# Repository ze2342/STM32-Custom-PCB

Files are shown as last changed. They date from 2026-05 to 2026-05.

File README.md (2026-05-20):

# STM32 Custom PCB Design

A custom STM32-based embedded system PCB designed in KiCad following professional PCB design practices inspired by Phil’s Lab.

## Overview

This project demonstrates the complete workflow of designing a professional embedded STM32 PCB from scratch instead of using ready-made development boards like the STM32 Blue Pill.

The PCB was designed with focus on:
- Clean routing
- Ground plane implementation
- Proper power distribution
- Compact embedded hardware layout
- Professional PCB engineering workflow

---

## Features

- STM32 microcontroller
- USB interface
- SWD programming/debugging header
- UART communication header
- BOOT mode switch
- I2C header
- Ground plane implementation
- Mounting holes
- Fully clean DRC
  - 0 Errors
  - 0 Warnings

---

## Tools Used

- KiCad
- STM32
- Git & GitHub

---

## PCB Preview

### Schematic
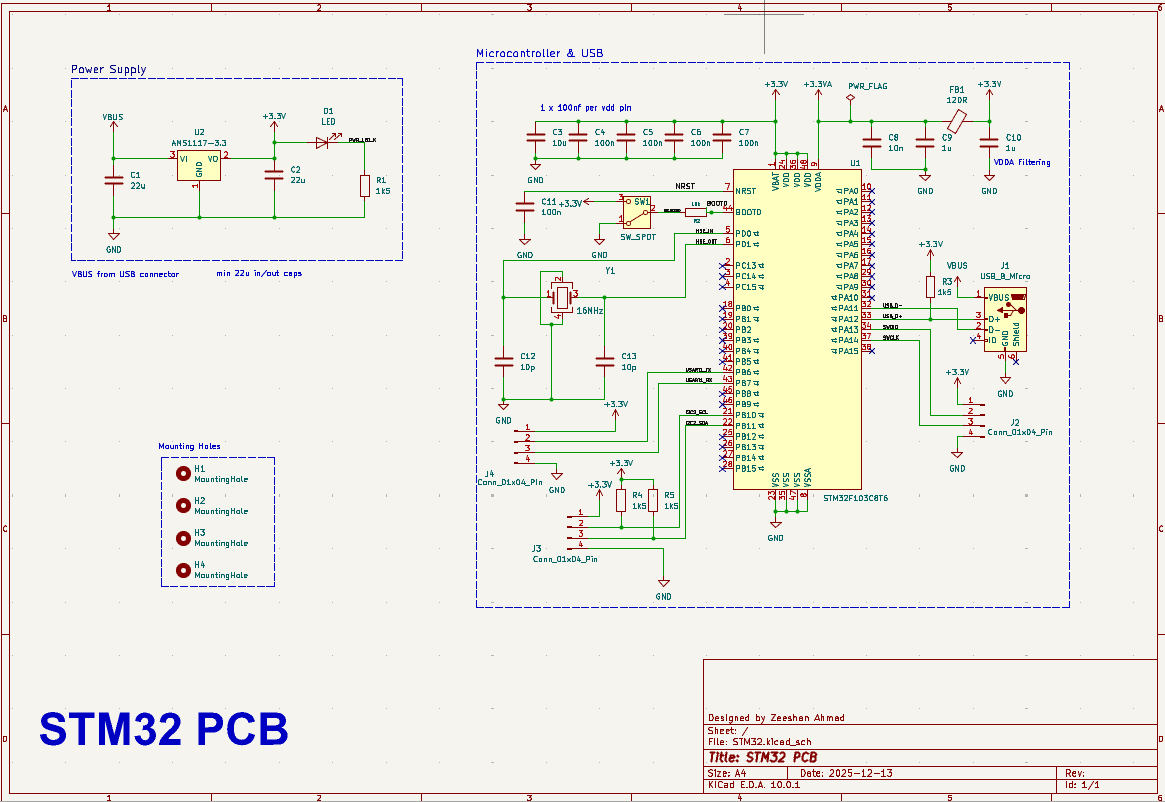
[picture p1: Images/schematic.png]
Schematic


### PCB Layout
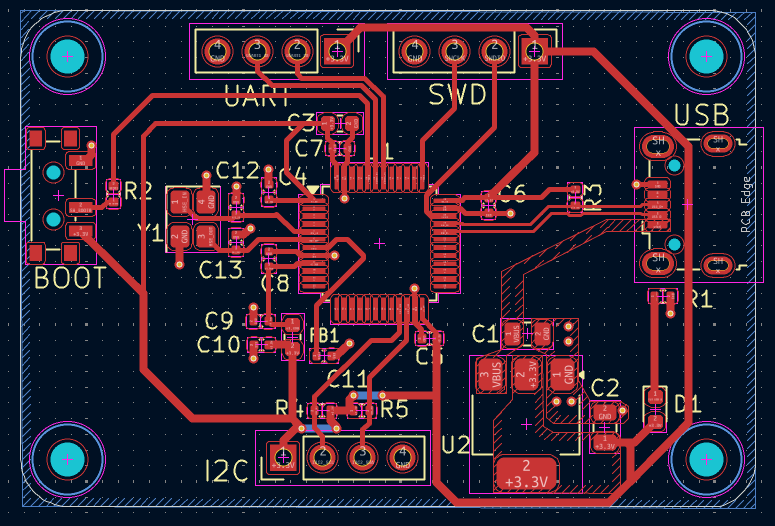
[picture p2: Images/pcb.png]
PCB Layout


### 3D View
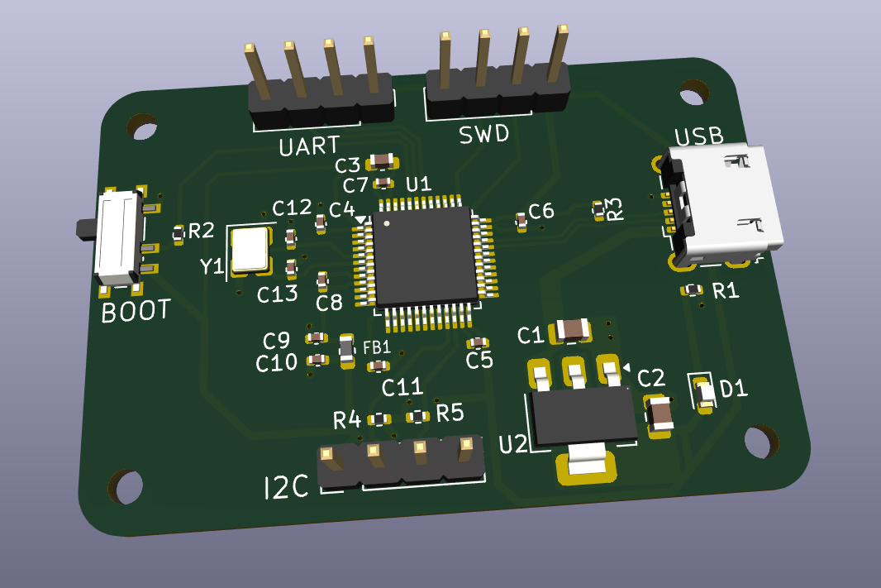
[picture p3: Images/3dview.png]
3D View


## Learning Outcomes

Through this project I learned:

- STM32 hardware design
- PCB routing techniques
- Ground plane usage
- Design Rule Check (DRC)
- Via sizing and routing
- Footprint customization
- USB and UART interfacing
- Embedded hardware workflow
- GitHub project management

---

## Folder Structure

```text
STM32-CUSTOM-BOARD/
│
├── KiCad/
├── Images/
├── README.md
└── LICENSE
```

---

## Future Improvements

- Add more GPIO breakout headers
- Add onboard sensors
- Add firmware examples
- Create a custom enclosure
- Add power protection circuitry

---

## Inspiration

This project was inspired by Phil’s Lab embedded hardware and PCB design tutorials.

---

## Author

Zeeshan Ahmad

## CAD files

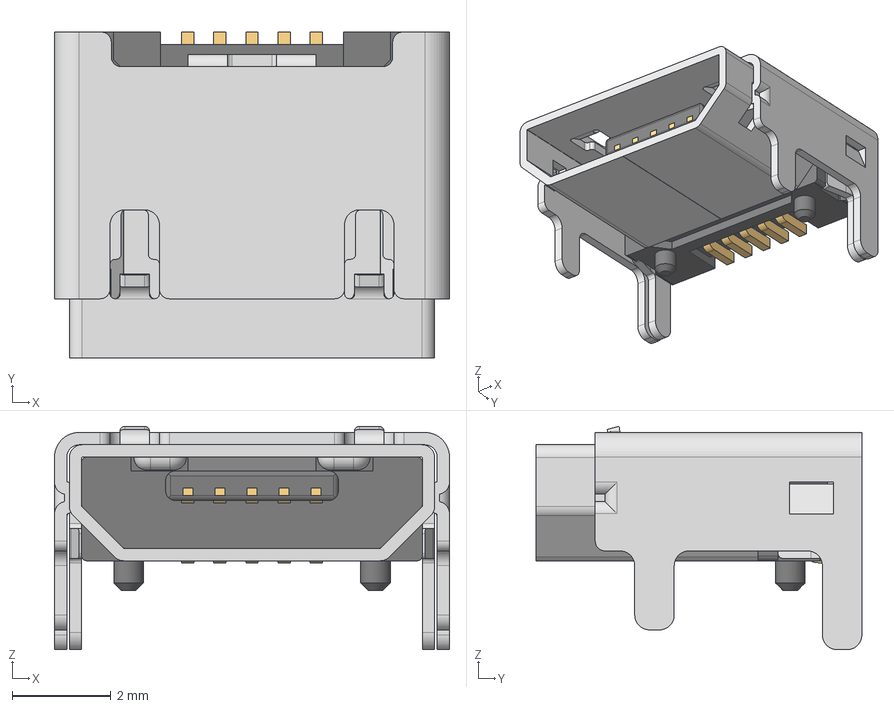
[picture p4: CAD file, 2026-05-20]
KiCad/629105150521 (rev1).stp
8.00 x 6.60 x 4.52 mm
629105150521_Housing
629105150521_Pin1 x 4
629105150521_Pin2
629105150521_Shielding2
629105150521_Shielding

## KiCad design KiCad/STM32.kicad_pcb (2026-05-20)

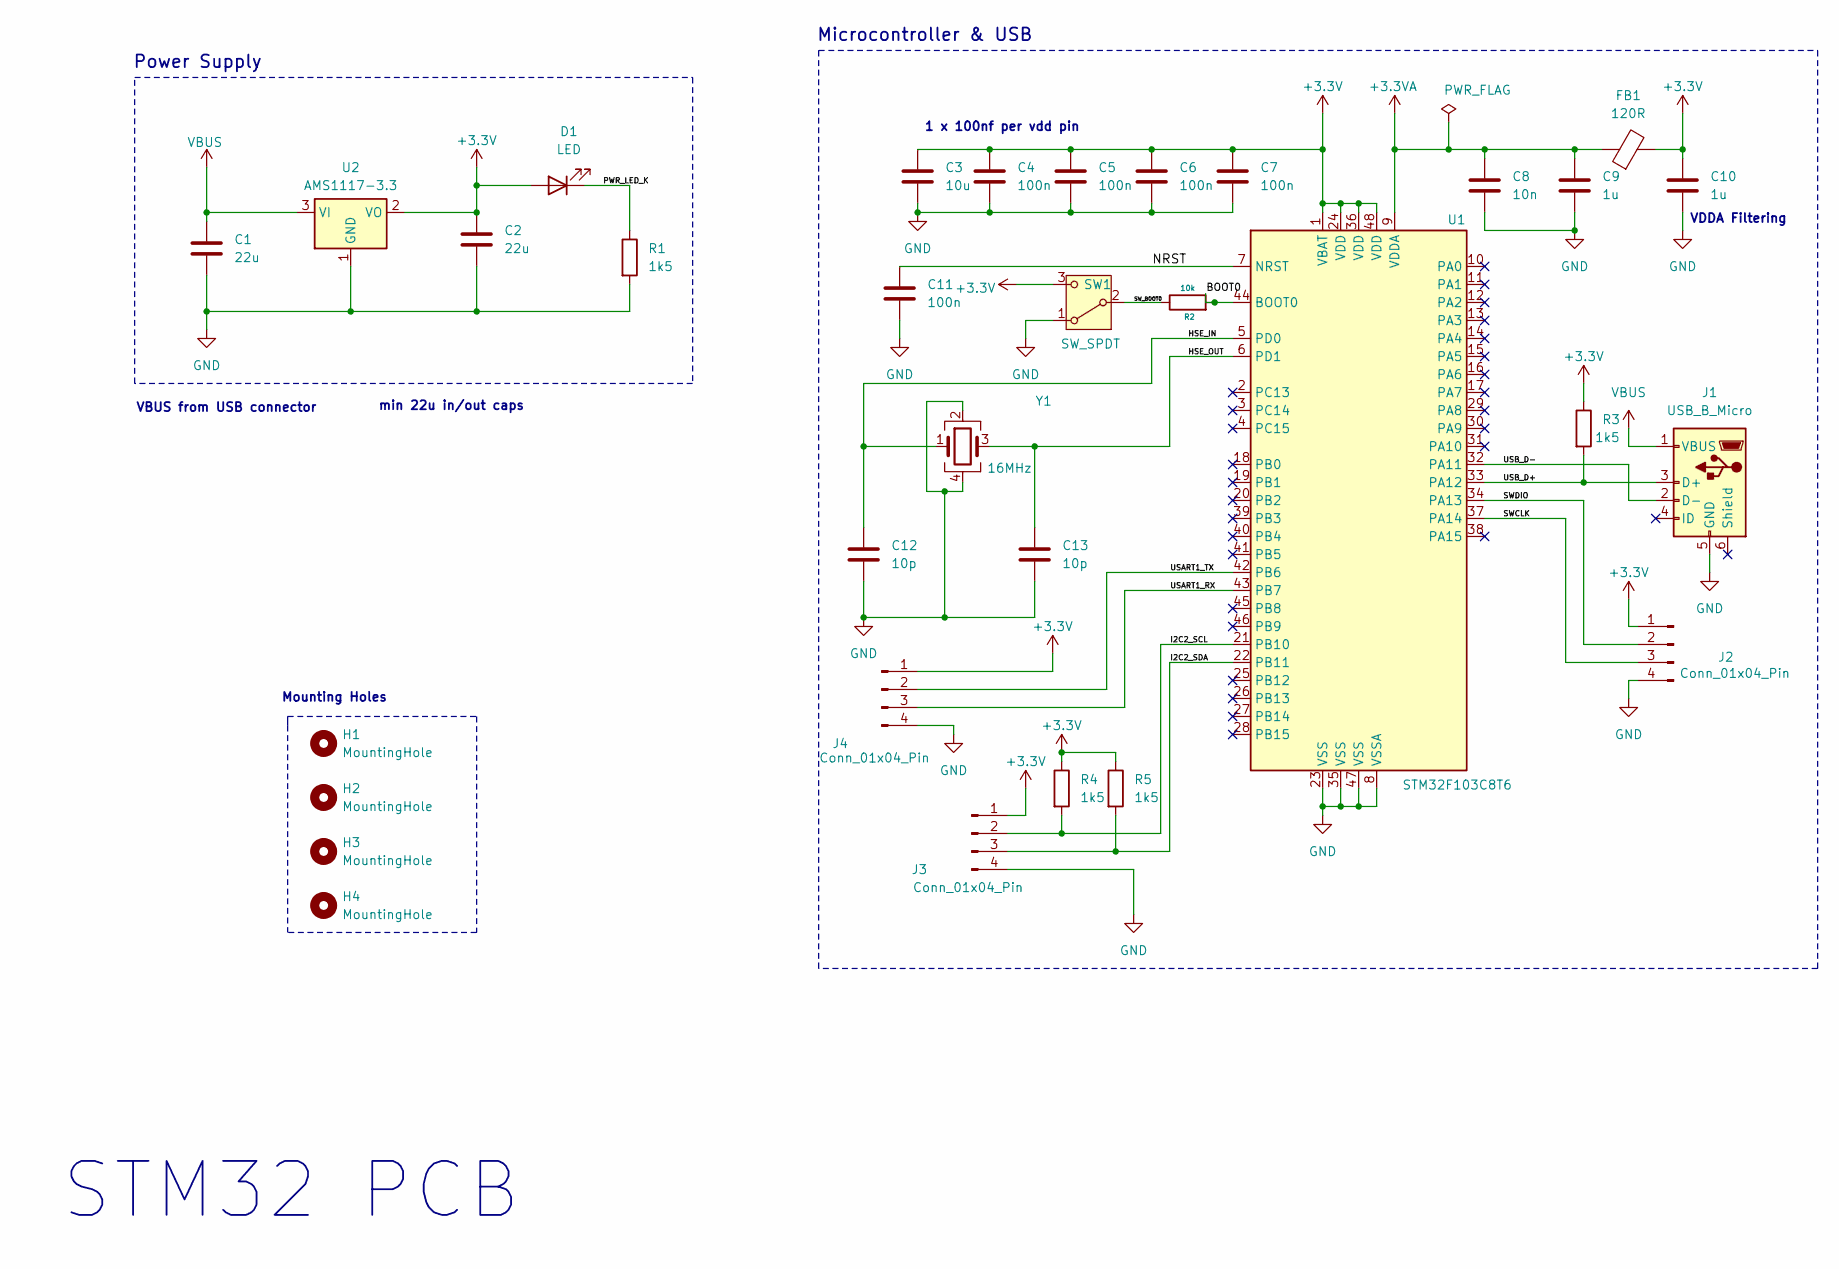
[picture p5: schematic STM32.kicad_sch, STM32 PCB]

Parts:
C1, C2: 22u; C_0805_2012Metric
C3: 10u; C_0603_1608Metric
C4, C5, C6, C7, C11: 100n; C_0402_1005Metric
C8: 10n; C_0402_1005Metric
C9, C10: 1u; C_0402_1005Metric
C12, C13: 10p; C_0402_1005Metric
D1: LED; LED_0603_1608Metric
FB1: 120R; L_0603_1608Metric
H1, H2, H3, H4: MountingHole; MountingHole_2.2mm_M2
J1: USB_B_Micro; USB_Micro-B_Wuerth_629105150521
J2, J3, J4: Conn_01x04_Pin; PinHeader_1x04_P2.54mm_Vertical
R1, R3, R4, R5: 1k5; R_0402_1005Metric
R2: 10k; R_0402_1005Metric
SW1: SW_SPDT; SW_SPDT_PCM12
U1: STM32F103C8T6; LQFP-48_7x7mm_P0.5mm
U2: AMS1117-3.3; SOT-223-3_TabPin2
Y1: 16MHz; Crystal_SMD_3225-4Pin_3.2x2.5mm

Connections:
+3.3V: C2.1, C3.1, C4.1, C5.1, C6.1, C7.1, C10.1, D1.2 (A), FB1.2, J2.1, J3.1, J4.1, R3.1, R4.1, R5.1, SW1.3 (C), U1.1 (VBAT), U1.24 (VDD), U1.36 (VDD), U1.48 (VDD), U2.2 (VO)
+3.3VA: C8.1, C9.1, FB1.1, U1.9 (VDDA)
/BOOT0: R2.2, U1.44 (BOOT0)
/HSE_IN: C12.1, U1.5 (PD0), Y1.1
/HSE_OUT: C13.1, U1.6 (PD1), Y1.3
/I2C2_SCL: J3.2, R4.2, U1.21 (PB10)
/I2C2_SDA: J3.3, R5.2, U1.22 (PB11)
/NRST: C11.1, U1.7 (NRST)
/PWR_LED_K: D1.1 (K), R1.1
/SWCLK: J2.3, U1.37 (PA14)
/SWDIO: J2.2, U1.34 (PA13)
/SW_BOOT0: R2.1, SW1.2 (B)
/USART1_RX: J4.3, U1.43 (PB7)
/USART1_TX: J4.2, U1.42 (PB6)
/USB_D+: J1.3 (D+), R3.2, U1.33 (PA12)
/USB_D-: J1.2 (D-), U1.32 (PA11)
GND: C1.2, C2.2, C3.2, C4.2, C5.2, C6.2, C7.2, C8.2, C9.2, C10.2, C11.2, C12.2, C13.2, J1.5 (GND), J2.4, J3.4, J4.4, R1.2, SW1.1 (A), U1.8 (VSSA), U1.23 (VSS), U1.35 (VSS), U1.47 (VSS), U2.1 (GND), Y1.2, Y1.4
VBUS: C1.1, J1.1 (VBUS), U2.3 (VI)

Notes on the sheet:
Mounting Holes
STM32 PCB
VDDA Filtering
VBUS from USB connector
1 x 100nf per vdd pin
min 22u in/out caps
Microcontroller & USB
Power Supply

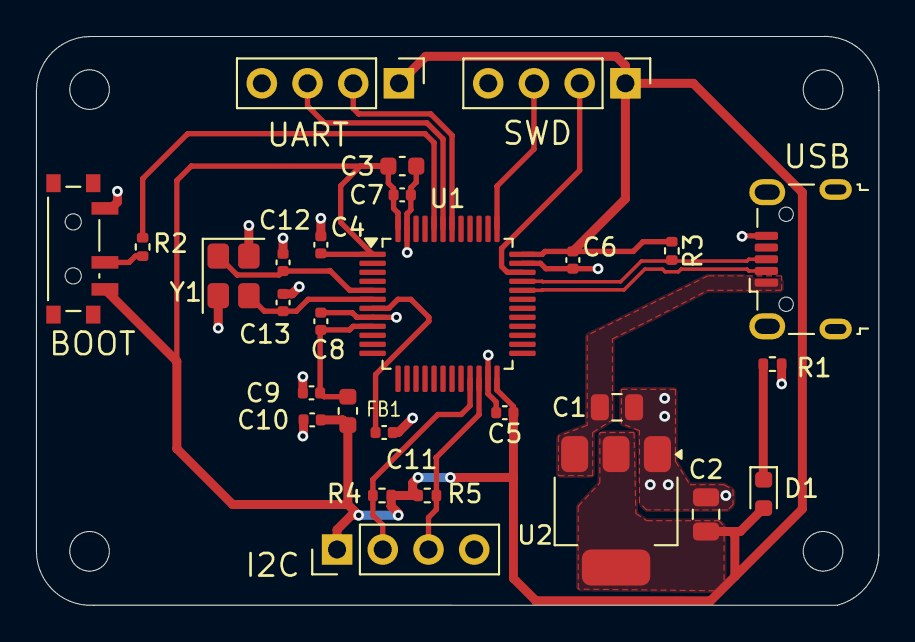
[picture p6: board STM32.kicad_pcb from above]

Board: 2 copper layers, 46.8 x 31.6 mm, 32 parts (0 on the bottom side), 18 nets.
